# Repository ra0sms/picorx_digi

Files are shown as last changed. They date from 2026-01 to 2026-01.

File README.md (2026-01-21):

# SDR receiver Pico RX for DIGI modes

This is a clone of Jon Dawson's project [PicoRX SDR](https://github.com/dawsonjon/PicoRX).

But I wanted to make a simple DIGI (WSPR, FT8) receiver. This modification works with PC and WSJT-X software by one USB Type-C cable. 3.5 mm audio output is just for sound control. Audio from receiver to PC goes through USB connection.

More information - https://ra0sms.com/picorx-digi-modes

Firmware for 3 type of boards - https://github.com/ra0sms/picorx_digi/tree/main/firmware

Gerber files - https://github.com/ra0sms/picorx_digi/blob/main/KiCad/pico_rx/gerber_picorxdigi.zip

More pictures - https://github.com/ra0sms/picorx_digi/tree/main/pics

Schematic - https://github.com/ra0sms/picorx_digi/blob/main/KiCad/pico_rx/pipicorx.pdf

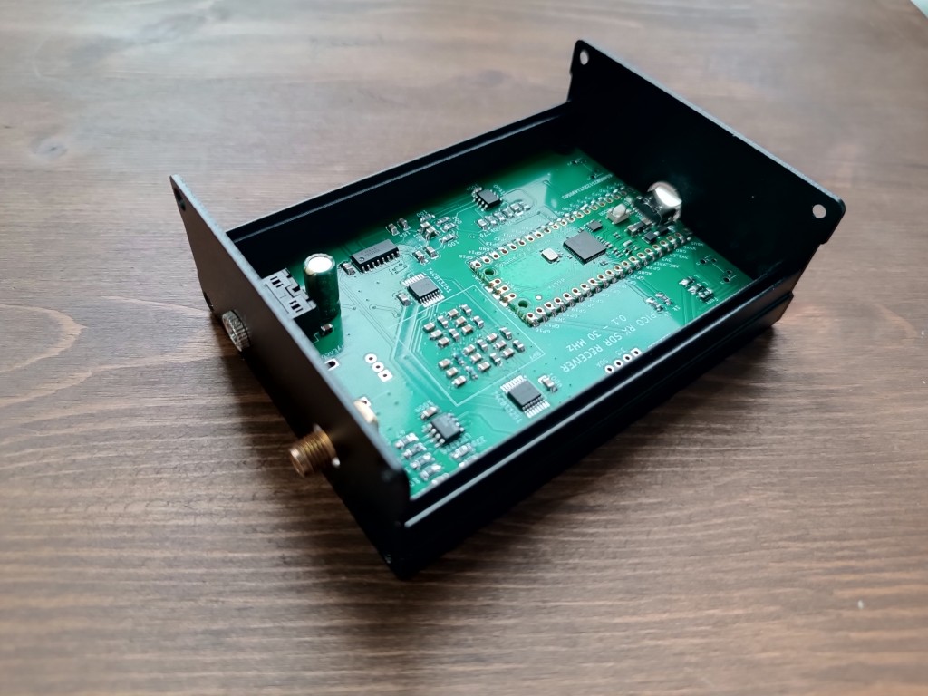
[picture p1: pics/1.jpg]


## Settings

You need to connect receiver to PC by USB cable. And select COM-port and Audio input like on the pictures below.

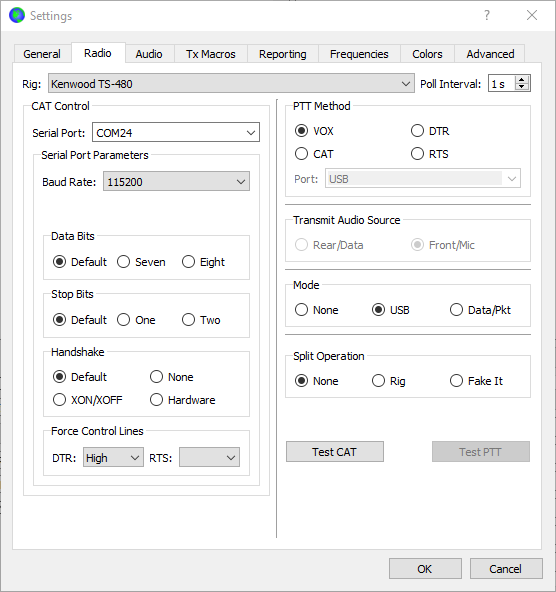
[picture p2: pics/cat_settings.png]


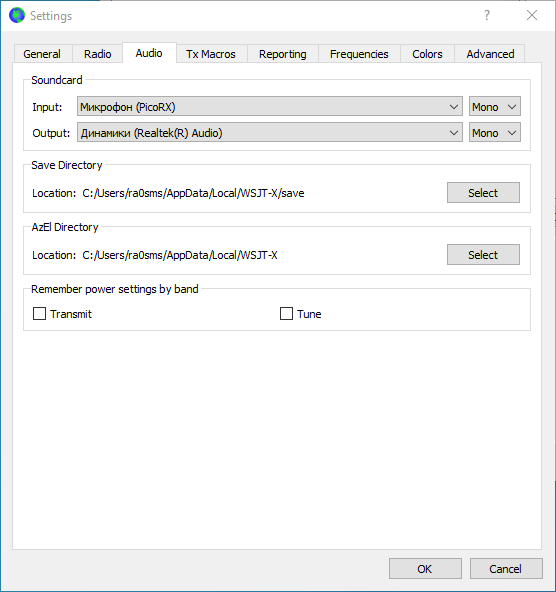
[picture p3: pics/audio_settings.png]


Or if you use FLrig software

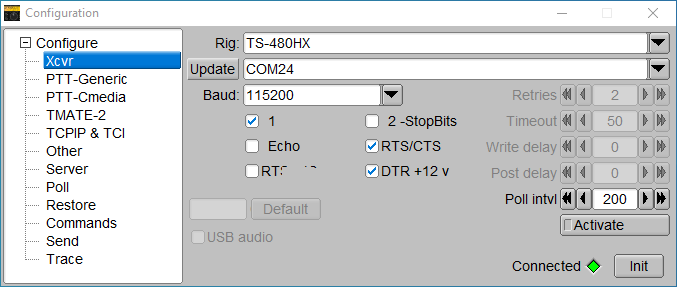
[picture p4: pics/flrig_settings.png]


Now you can see decodes.

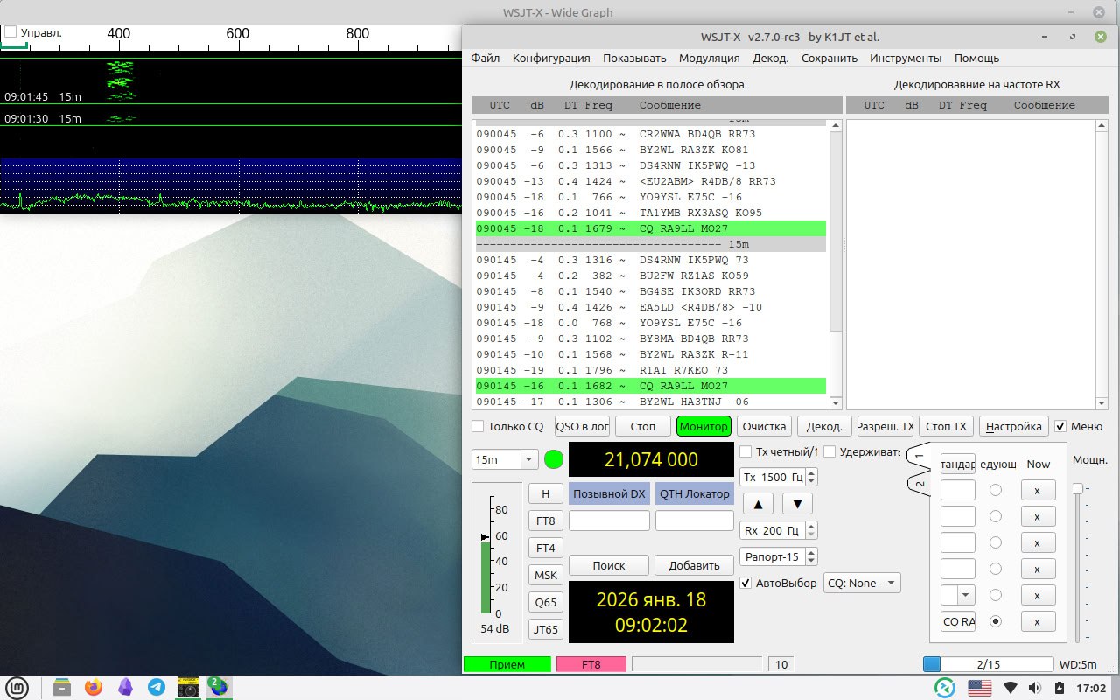
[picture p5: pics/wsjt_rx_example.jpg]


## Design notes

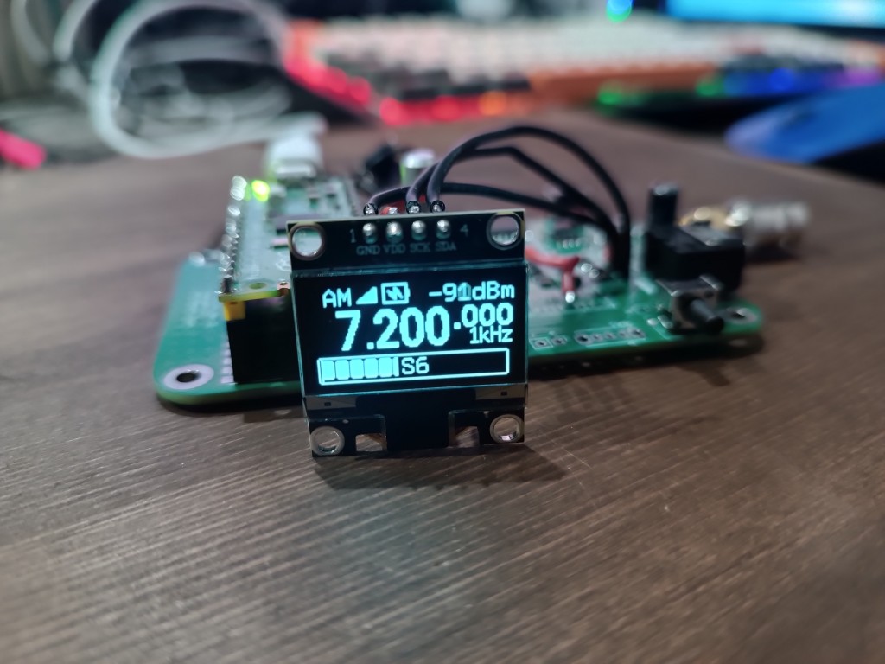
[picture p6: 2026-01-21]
pics/pipicorx_first.jpg

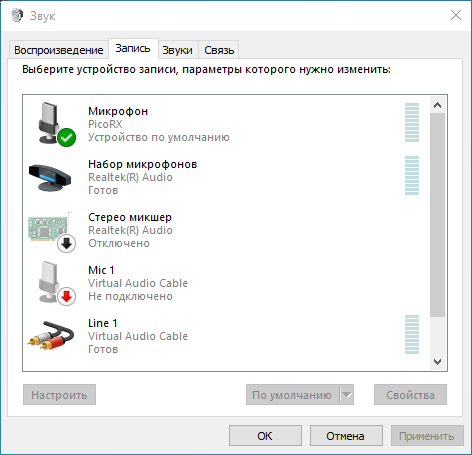
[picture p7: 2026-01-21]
pics/audio_win10.png

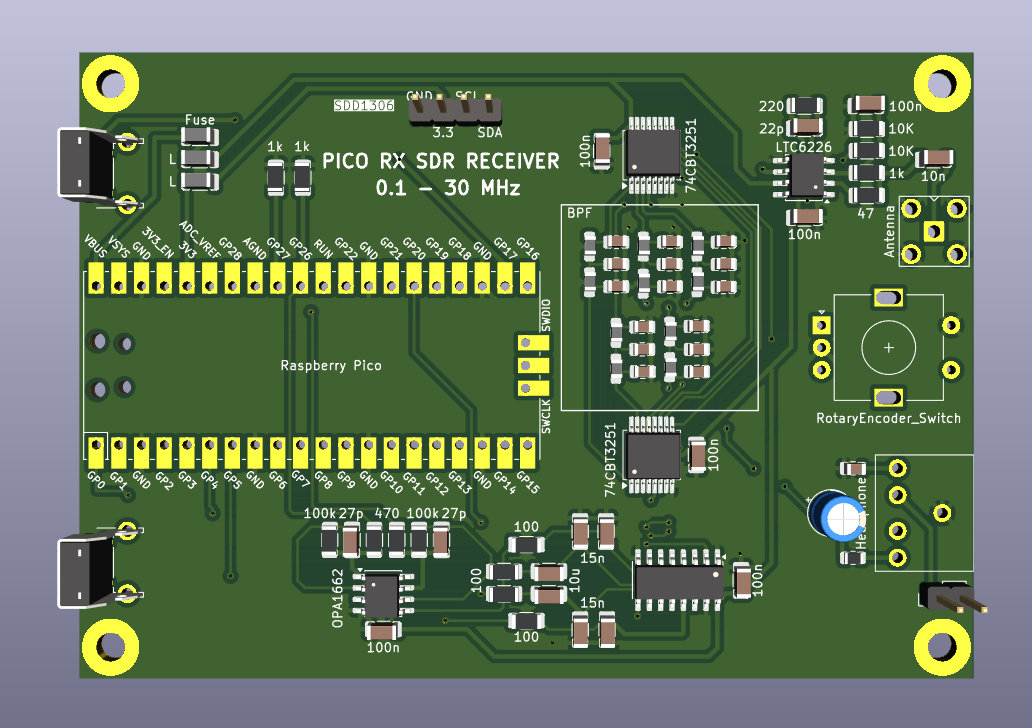
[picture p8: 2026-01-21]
pics/pico_rx_3D.png

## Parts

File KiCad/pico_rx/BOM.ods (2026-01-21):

Item | Qty | Reference(s) | Value | Footprint
1 | 1 | C1 | 10n | Capacitor_SMD:C_0805_2012Metric
2 | 6 | C2, C3, C10, C17, C24, C25 | 100n | Capacitor_SMD:C_0805_2012Metric | https://uk.farnell.com/murata/grm2195c1h103ja01d/cap-0-01-f-50v-5-c0g-np0-0805/dp/8820074
3 | 2 | C4, C11 | 10u | Capacitor_SMD:C_0805_2012Metric
4 | 1 | C5 | 22p | Capacitor_SMD:C_0805_2012Metric | https://uk.farnell.com/yageo/cc0805jrnpo9bn220/cap-22pf-50v-5-c0g-np0-0805/dp/1362555
5 | 2 | C6, C9 | 680p | Capacitor_SMD:C_0805_2012Metric | https://uk.farnell.com/multicomp/mc0805n681j101ct/cap-680pf-100v-5-c0g-np0-0805/dp/1759286
6 | 4 | C7, C13, C14, C15 | 1n | Capacitor_SMD:C_0805_2012Metric | https://uk.farnell.com/multicomp/mc0805n102j101ct/cap-1000pf-100v-5-c0g-np0-0805/dp/1759288
8 | 1 | C12 | 470p | Capacitor_SMD:C_0805_2012Metric | https://uk.farnell.com/multicomp/mca0805c471jct/cap-470pf-100v-5-c0g-np0-0805/dp/9406298
9 | 2 | C8, C16 | 330p | Capacitor_SMD:C_0805_2012Metric | https://uk.farnell.com/multicomp/mc0805n102j101ct/cap-1000pf-100v-5-c0g-np0-0805/dp/1759288
10 | 2 | C19, C22 | 1.5n | Capacitor_SMD:C_0805_2012Metric | https://uk.farnell.com/tdk/cga4c2c0g2a152j060aa/cap-1500pf-100v-5-c0g-np0-0805/dp/2210934
11 | 1 | C21 | 2.2n | Capacitor_SMD:C_0805_2012Metric | https://uk.farnell.com/tdk/cga4f2np02a222j085aa/cap-aec-q200-2200pf-100v-mlcc/dp/3651337
12 | 4 | C26, C27, C28, C29 | 15n | Capacitor_SMD:C_0805_2012Metric | https://uk.farnell.com/tdk/c2012c0g2a153j085ac/cap-0-015-f-100v-5-c0g-np0-0805/dp/2906792
13 | 2 | C30, C31 | 27p | Capacitor_SMD:C_0805_2012Metric | https://uk.farnell.com/multicomp/mc0805n270j500ct/cap-27pf-50v-5-c0g-np0-0805/dp/1759196
14 | 1 | C34 | 470n | Capacitor_SMD:C_0805_2012Metric | https://uk.farnell.com/tdk/cga4j2x7r2a153k125aa/cap-0-015-f-100v-10-x7r-0805/dp/2210963
15 | 2 | C36, C38 | 3.3n | Capacitor_SMD:C_0805_2012Metric | https://uk.farnell.com/tdk/cga4j2c0g2a332j125aa/cap-3300pf-100v-5-c0g-np0-0805/dp/2210955
16 | 1 | C37 | 4.7n | Capacitor_SMD:C_0805_2012Metric | https://uk.farnell.com/tdk/c2012np02a472j125aa/cap-4700pf-100v-mlcc-0805/dp/3651052
17 | 1 | C39 | 100u | Capacitor_Tantalum_SMD:CP_EIA-3528-21_Kemet-B | https://uk.farnell.com/kemet/t591b107m004ate045/cap-100uf-4v-tant-polymer-case/dp/3521846
18 | 2 | FB1, FB2 | Ferrite_Bead | Inductor_SMD:L_0805_2012Metric | https://uk.farnell.com/tdk/mmz2012y102b/ferrite-bead-0-3ohm-500ma-0805/dp/1669727
20 | 1 | J1 | Speaker | Connector_PinHeader_2.54mm:PinHeader_1x02_P2.54mm_Vertical | https://uk.farnell.com/pro-signal/abs-245-rc/speaker-0-5w-10khz-8-ohm/dp/2783054
21 | 1 | J2 | Headphone | reciever:jack3.5mm switched | https://uk.farnell.com/cliff-electronic-components/fc68133/stereo-jack-3-5mm-5pos-pcb/dp/2518190
22 | 1 | J4 | I2C Display | reciever:SDD1306 | https://www.amazon.co.uk/dp/B08ZKW6KM1?ref_=pe_27063361_487360311_302_E_DDE_dt_1&th=1
23 | 1 | J5 | Antenna | Connector_Coaxial:SMA_Samtec_SMA-J-P-X-ST-EM1_EdgeMount | https://uk.farnell.com/rf-solutions/con-sma-edge-s/sma-female-connector-pcb-edge/dp/3498459
24 | 1 | J6 | Battery | Connector_PinHeader_2.54mm:PinHeader_1x02_P2.54mm_Vertical | https://www.amazon.co.uk/dp/B00OK6BFGS/ref=pe_27063361_485629781_TE_item
25 | 2 | L1, L2 | 330n | Inductor_SMD:L_0805_2012Metric_Pad1.05x1.20mm_HandSolder | https://uk.farnell.com/multicomp/mcft000101/inductor-330nh-0603/dp/1711816
26 | 2 | L3, L4 | 1u | Inductor_SMD:L_0805_2012Metric_Pad1.05x1.20mm_HandSolder | https://uk.farnell.com/multicomp/mcft000128/inductor-1000nh-0805/dp/1711847
27 | 2 | L5, L13 | 220n | Inductor_SMD:L_0805_2012Metric_Pad1.05x1.20mm_HandSolder | https://uk.farnell.com/multicomp/mcft000120/inductor-220nh-0805/dp/1711838
28 | 2 | L6, L7 | 2.2u | Inductor_SMD:L_0805_2012Metric_Pad1.05x1.20mm_HandSolder | https://uk.farnell.com/multicomp/mcft000130/inductor-2200nh-0805/dp/1711849
29 | 2 | L8, L9 | 4.7u | Inductor_SMD:L_0805_2012Metric_Pad1.05x1.20mm_HandSolder | https://uk.farnell.com/multicomp/mcft000132/inductor-4700nh-0805/dp/1711851
30 | 1 | R1 | 47 | Resistor_SMD:R_0805_2012Metric | https://uk.farnell.com/walsin/wf08p47r0ftl/res-47r-1-0-25w-0805-thick-film/dp/2670099
31 | 2 | R2, R10 | 10K | Resistor_SMD:R_0805_2012Metric | https://uk.farnell.com/vishay/crcw080510k0fkta/res-10k-1-0-125w-0805-thick-film/dp/1652909
32 | 5 | R3, R4, R5, R6, R9 | 100 | Resistor_SMD:R_0805_2012Metric | https://uk.farnell.com/multicomp/mc01w08051100r/res-100r-1-0-1w-0805-thick-film/dp/9332375
33 | 2 | R7, R8 | 100k | Resistor_SMD:R_0805_2012Metric | https://uk.farnell.com/bourns/cr0805-fx-1003elf/res-100k-1-0-125w-0805-thick-film/dp/2333538
34 | 1 | R11 | 220 | Resistor_SMD:R_0805_2012Metric | https://uk.farnell.com/bourns/cr0805-fx-2200elf/res-220r-1-0-125w-0805-thick-film/dp/4153657
35 | 3 | R12, R15, R16 | 1k | Resistor_SMD:R_0805_2012Metric | https://uk.farnell.com/multicomp/mcwr08x1001ftl/res-1k-1-0-125w-0805-thick-film/dp/2447587
36 | 2 | R13, R14 | 470 | Resistor_SMD:R_0805_2012Metric | https://uk.farnell.com/multicomp/mcwr08x4700ftl/res-470r-1-0-125w-thick-film/dp/2447662
37 | 1 | SW1 | RotaryEncoder_Switch | Rotary_Encoder:RotaryEncoder_Alps_EC11E-Switch_Vertical_H20mm | https://uk.farnell.com/tt-electronics-bi-technologies/en11-hsm1af15/incremental-encoder/dp/1782717
38 | 2 | SW2, SW3 | SW_Push | Button_Switch_THT:SW_Tactile_SPST_Angled_PTS645Vx31-2LFS | https://uk.farnell.com/alps/skhhlma010/switch-tactile-pcb-r-a-0-98n/dp/1656426
39 | 1 | SW4 | SW_SPDT | Button_Switch_THT:SW_Slide_1P2T_CK_OS102011MS2Q | https://uk.farnell.com/c-k-components/os102011ma1qn1/switch-spdt-0-1a-12v-pcb-r-a/dp/1201431
40 | 2 | U1, U2 | 74CBT3251 | Package_SO:SOIC-16_3.9x9.9mm_P1.27mm | https://www.digikey.co.uk/en/products/detail/SN74CBT3251DR/296-49883-1-ND/9462753?so=64190438
41 | 1 | U3 | LTC6227 | Package_SO:MSOP-8-1EP_3x3mm_P0.65mm_EP1.68x1.88mm | https://uk.farnell.com/analog-devices/ltc6227ims8e-pbf/op-amp-420mhz-40-to-85deg-c-msop/dp/4021288
42 | 1 | U4 | FST3253 | Package_SO:SOIC-16_3.9x9.9mm_P1.27mm | https://www.digikey.co.uk/en/products/detail/rochester-electronics-llc/FST3253MX/12618585
43 | 1 | U5 | Pico | reciever:RPi_Pico_SMD_TH | https://thepihut.com/products/raspberry-pi-pico?variant=41925332533443&currency=GBP
44 | 1 | U6 | LTC6226xS8 | Package_SO:SO-8_3.9x4.9mm_P1.27mm | https://uk.farnell.com/analog-devices/ltc6226hs8-pbf/op-amp-420mhz-40-to-125deg-c-nsoic/dp/4021281

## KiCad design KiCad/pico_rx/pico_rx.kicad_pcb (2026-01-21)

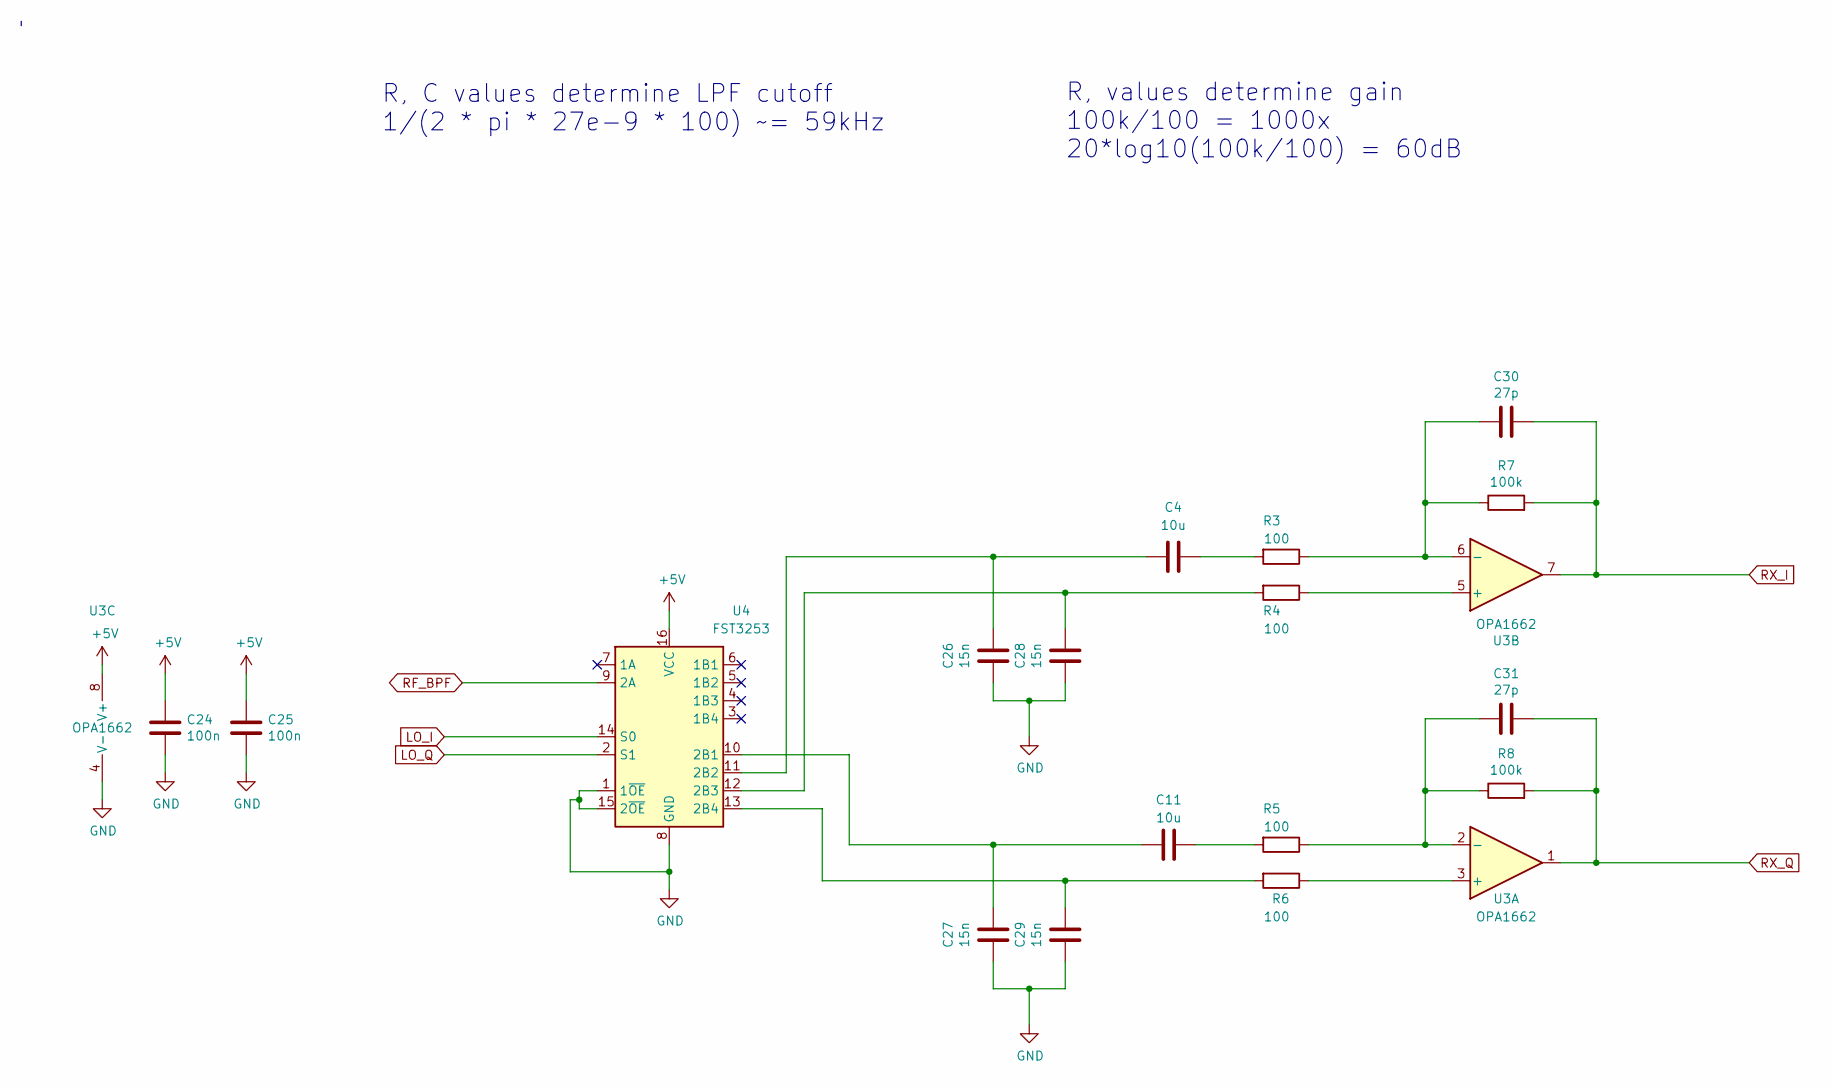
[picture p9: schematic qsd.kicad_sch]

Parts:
C4, C11: 10u; C_1206_3216Metric
C24, C25: 100n; C_1206_3216Metric
C26, C27, C28, C29: 15n; C_1206_3216Metric
C30, C31: 27p; C_1206_3216Metric
R3, R4, R5, R6: 100; R_1206_3216Metric
R7, R8: 100k; R_1206_3216Metric
U3: OPA1662; SO-8_3.9x4.9mm_P1.27mm
U4: FST3253; SOIC-16_3.9x9.9mm_P1.27mm

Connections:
+5V: C24.1, C25.1, U3.8 (V+), U4.16 (VCC); also elsewhere on the board
GND: C24.2, C25.2, C26.1, C27.1, C28.1, C29.1, U3.4 (V-), U4.1 (1~OE), U4.8 (GND), U4.15 (2~OE); also elsewhere on the board
LO_I: U4.14 (S0); also elsewhere on the board
LO_Q: U4.2 (S1); also elsewhere on the board
unnamed: C4.1, R3.2
unnamed: C11.1, R5.2
unnamed: R6.1, U3.3 (+)
unnamed: C31.1, R5.1, R8.1, U3.2 (-)
unnamed: R4.1, U3.5 (+)
unnamed: C30.1, R3.1, R7.1, U3.6 (-)
unnamed: C11.2, C27.2, U4.10 (2B1)
unnamed: C4.2, C26.2, U4.11 (2B2)
unnamed: C28.2, R4.2, U4.12 (2B3)
unnamed: C29.2, R6.2, U4.13 (2B4)
RF_BPF: U4.9 (2A); also elsewhere on the board
RX_I: C30.2, R7.2, U3.7; also elsewhere on the board
RX_Q: C31.2, R8.2, U3.1; also elsewhere on the board

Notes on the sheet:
R, values determine gain 100k/100 = 1000x 20*log10(100k/100) = 60dB
R, C values determine LPF cutoff 1/(2 * pi * 27e-9 * 100) ~= 59kHz

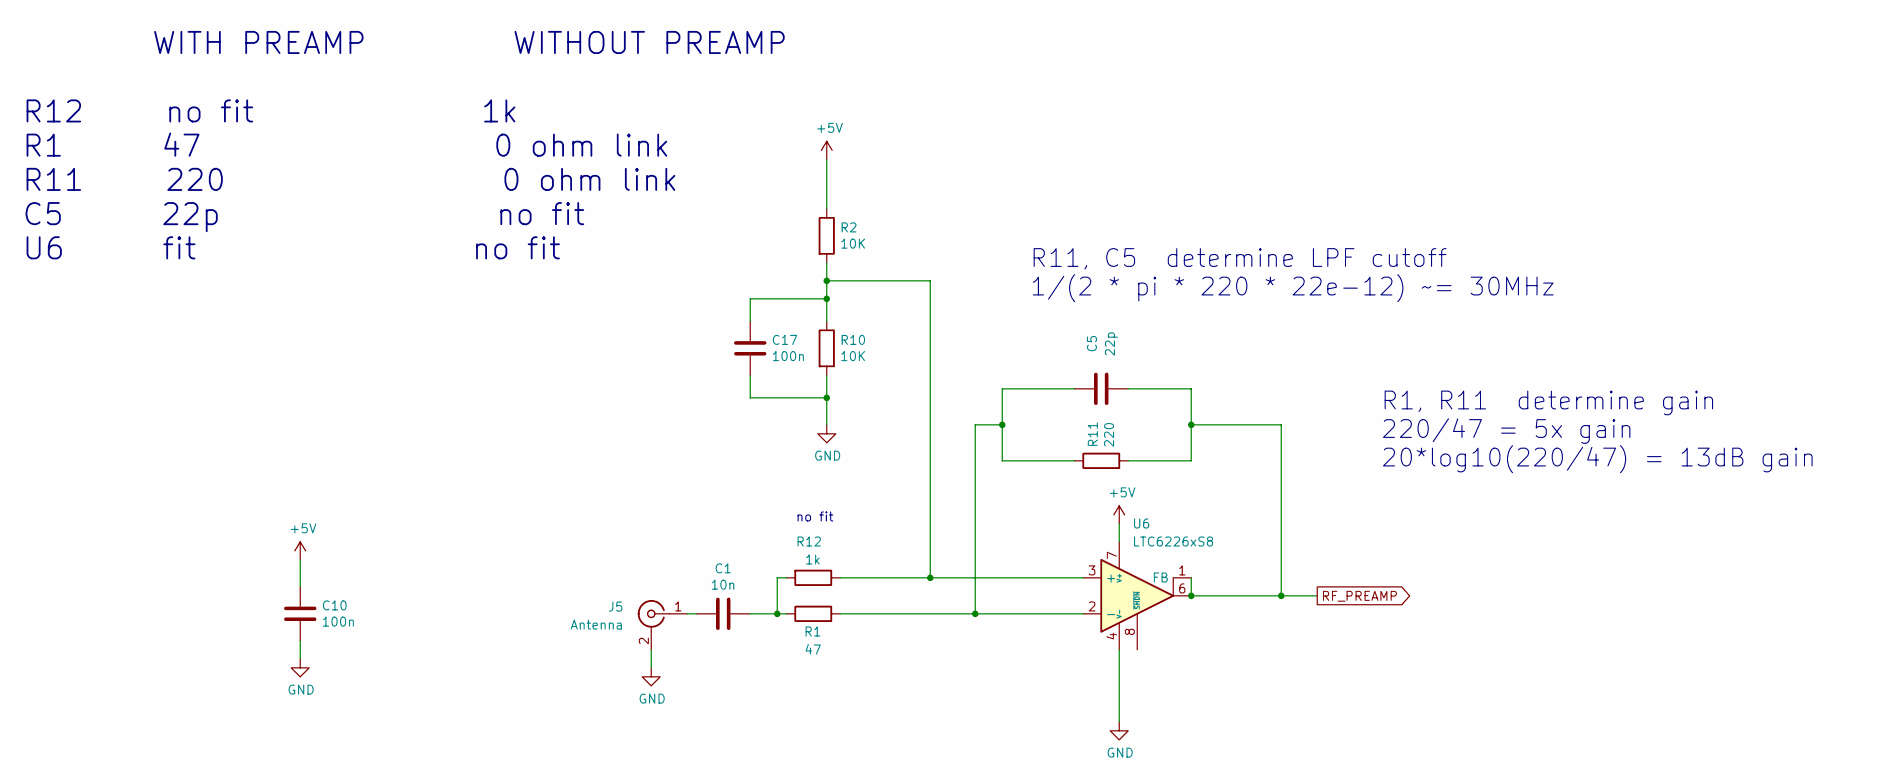
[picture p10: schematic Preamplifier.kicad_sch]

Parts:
C1: 10n; C_1206_3216Metric
C5: 22p; C_1206_3216Metric
C10, C17: 100n; C_1206_3216Metric
J5: Antenna; SMA_BAT_Wireless_BWSMA-KWE-Z001
R1: 47; R_1206_3216Metric
R2, R10: 10K; R_1206_3216Metric
R11: 220; R_1206_3216Metric
R12: 1k; R_1206_3216Metric
U6: LTC6226xS8; SO-8_3.9x4.9mm_P1.27mm

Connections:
+5V: C10.1, R2.1, U6.7 (V+); also elsewhere on the board
GND: C10.2, C17.2, J5.2 (Ext), R10.2, U6.4 (V-), U6.5 (V-); also elsewhere on the board
unnamed: C1.1, R1.1, R12.2
unnamed: C1.2, J5.1 (In)
unnamed: C17.1, R2.2, R10.1, R12.1, U6.3 (+)
unnamed: C5.1, R1.2, R11.1, U6.2 (-)
RF_PREAMP: C5.2, R11.2, U6.1 (FB), U6.6; also elsewhere on the board

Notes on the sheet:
no fit
R11, C5 determine LPF cutoff 1/(2 * pi * 220 * 22e-12) ~= 30MHz
WITH PREAMP WITHOUT PREAMP R12 no fit 1k R1 47 0 ohm link R11 220 0 ohm link C5 22p no fit U6 fit no fit
R1, R11 determine gain 220/47 = 5x gain 20*log10(220/47) = 13dB gain

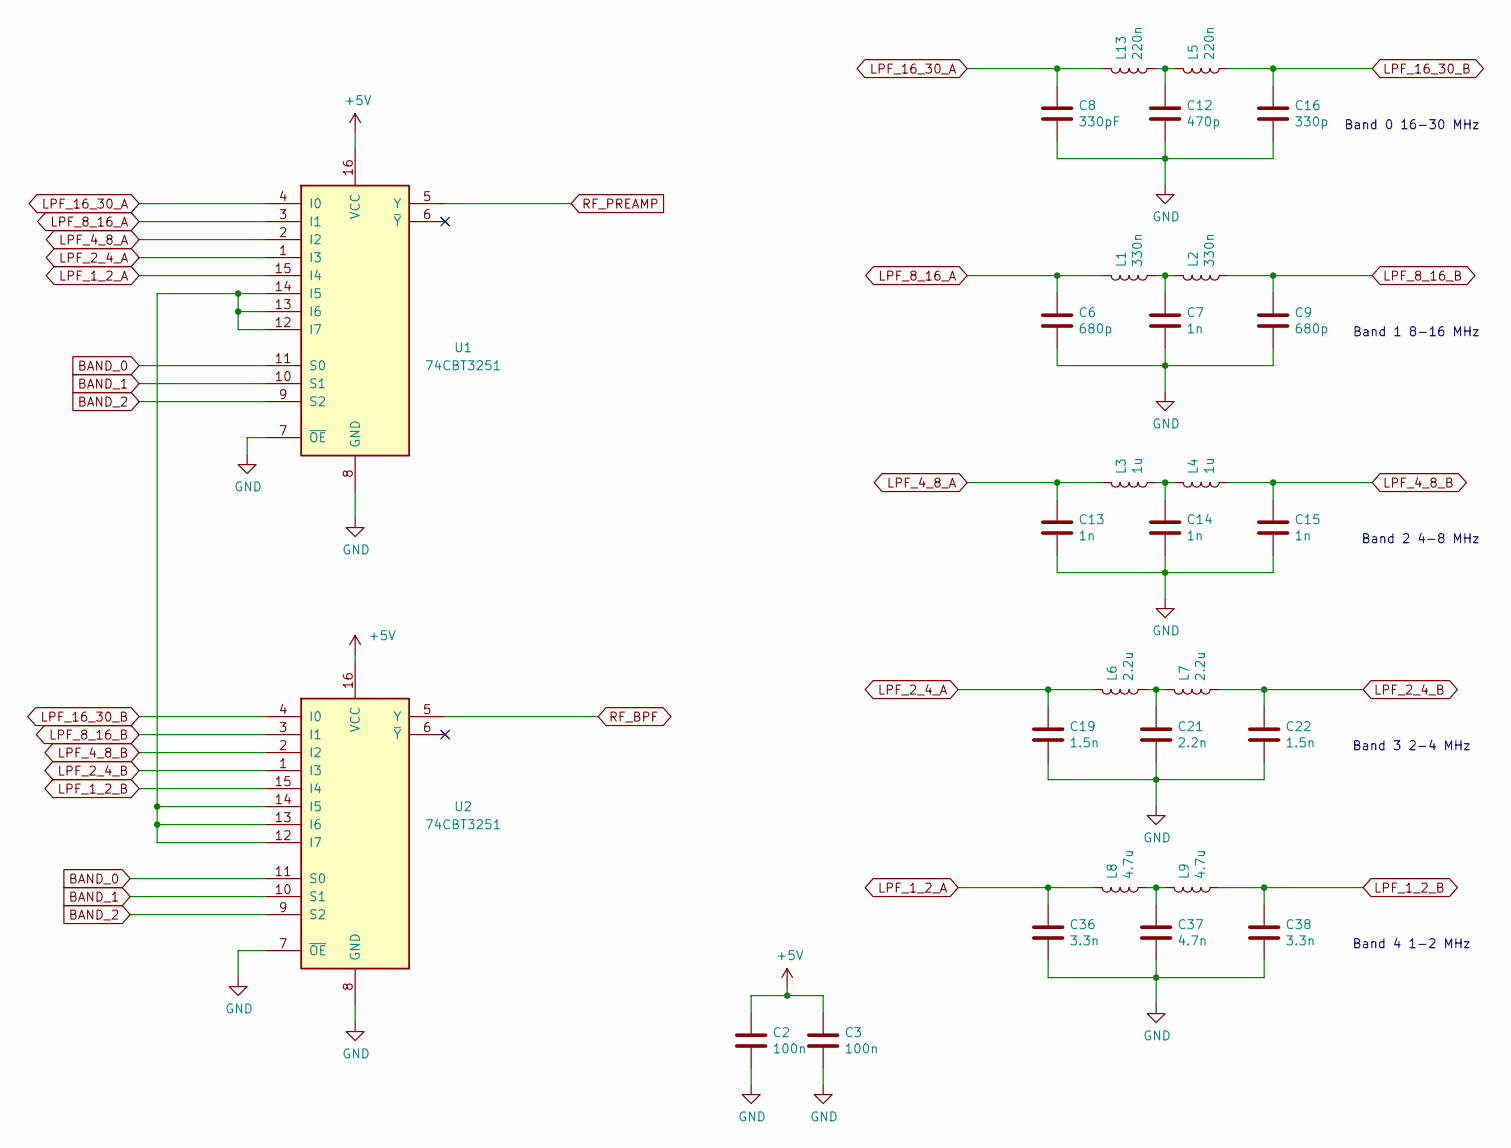
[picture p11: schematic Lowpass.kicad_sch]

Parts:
C2, C3: 100n; C_1206_3216Metric
C6, C9: 680p; C_0805_2012Metric
C7, C13, C14, C15: 1n; C_0805_2012Metric
C8: 330pF; C_0805_2012Metric
C12: 470p; C_0805_2012Metric
C16: 330p; C_0805_2012Metric
C19, C22: 1.5n; C_0805_2012Metric
C21: 2.2n; C_0805_2012Metric
C36, C38: 3.3n; C_0805_2012Metric
C37: 4.7n; C_0805_2012Metric
L1, L2: 330n; L_0805_2012Metric_Pad1.05x1.20mm_HandSolder
L3, L4: 1u; L_0805_2012Metric_Pad1.05x1.20mm_HandSolder
L5, L13: 220n; L_0805_2012Metric_Pad1.05x1.20mm_HandSolder
L6, L7: 2.2u; L_0805_2012Metric_Pad1.05x1.20mm_HandSolder
L8, L9: 4.7u; L_0805_2012Metric_Pad1.05x1.20mm_HandSolder
U1, U2: 74CBT3251; SSOP-16_5.3x6.2mm_P0.65mm

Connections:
+5V: C2.1, C3.1, U1.16 (VCC), U2.16 (VCC); also elsewhere on the board
BAND_0: U1.11 (S0), U2.11 (S0); also elsewhere on the board
BAND_1: U1.10 (S1), U2.10 (S1); also elsewhere on the board
BAND_2: U1.9 (S2), U2.9 (S2); also elsewhere on the board
GND: C2.2, C3.2, C6.1, C7.1, C8.1, C9.1, C12.1, C13.1, C14.1, C15.1, C16.1, C19.1, C21.1, C22.1, C36.1, C37.1, C38.1, U1.7 (~OE), U1.8 (GND), U2.7 (~OE), U2.8 (GND); also elsewhere on the board
LPF_1_2_A: C36.2, L8.2, U1.15 (I4)
LPF_1_2_B: C38.2, L9.1, U2.15 (I4)
LPF_2_4_A: C19.2, L6.2, U1.1 (I3)
LPF_2_4_B: C22.2, L7.1, U2.1 (I3)
LPF_4_8_A: C13.2, L3.2, U1.2 (I2)
LPF_4_8_B: C15.2, L4.1, U2.2 (I2)
LPF_8_16_A: C6.2, L1.2, U1.3 (I1)
LPF_8_16_B: C9.2, L2.1, U2.3 (I1)
LPF_16_30_A: C8.2, L13.2, U1.4 (I0)
LPF_16_30_B: C16.2, L5.1, U2.4 (I0)
unnamed: C7.2, L1.1, L2.2
unnamed: C12.2, L5.2, L13.1
unnamed: C14.2, L3.1, L4.2
unnamed: C21.2, L6.1, L7.2
unnamed: C37.2, L8.1, L9.2
unnamed: U1.12 (I7), U1.13 (I6), U1.14 (I5), U2.12 (I7), U2.13 (I6), U2.14 (I5)
RF_BPF: U2.5 (Y); also elsewhere on the board
RF_PREAMP: U1.5 (Y); also elsewhere on the board

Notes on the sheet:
Band 2 4-8 MHz
Band 4 1-2 MHz
Band 1 8-16 MHz
Band 3 2-4 MHz
Band 0 16-30 MHz

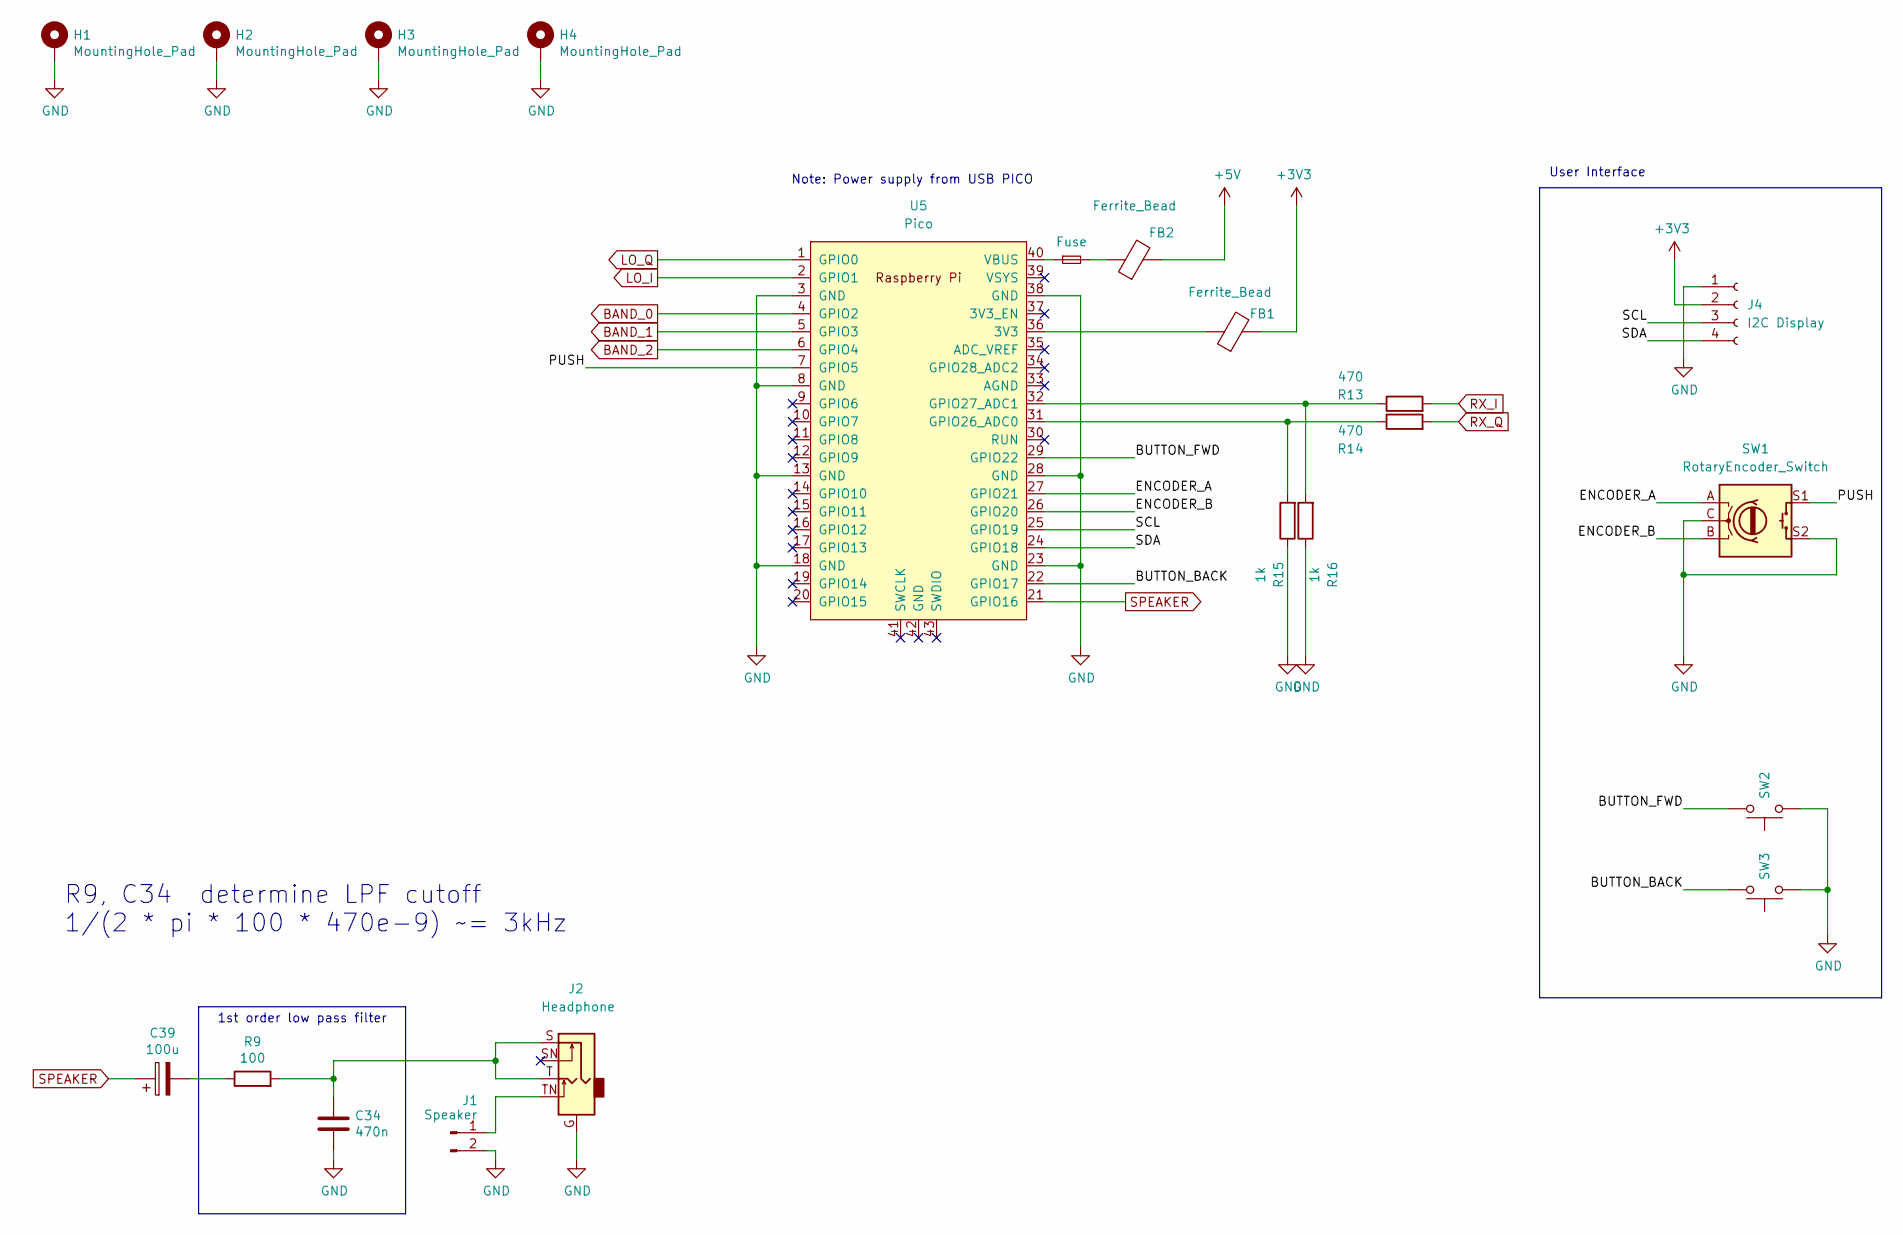
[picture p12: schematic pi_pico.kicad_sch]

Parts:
C34: 470n; C_0805_2012Metric
C39: 100u; CP_Radial_D5.0mm_P2.50mm
F1: Fuse; L_1206_3216Metric
FB1, FB2: Ferrite_Bead; L_1206_3216Metric
H1, H2, H3, H4: MountingHole_Pad; MountingHole_3.2mm_M3_Pad
J1: Speaker; PinHeader_1x02_P2.54mm_Vertical
J2: Headphone; jack3.5mm switched
J4: I2C Display; SDD1306
R9: 100; R_0805_2012Metric
R13, R14: 470; R_1206_3216Metric
R15, R16: 1k; R_1206_3216Metric
SW1: RotaryEncoder_Switch; RotaryEncoder_Alps_EC11E-Switch_Vertical_H20mm
SW2, SW3: SW_Push; SW_Tactile_SPST_Angled_PTS645Vx31-2LFS
U5: Pico; RPi_Pico_SMD_TH

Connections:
+3V3: FB1.2, J4.2
+5V: FB2.2; also elsewhere on the board
/PI Pico/BUTTON_BACK: SW3.2, U5.22 (GPIO17)
/PI Pico/BUTTON_FWD: SW2.2, U5.29 (GPIO22)
/PI Pico/ENCODER_A: SW1.A, U5.27 (GPIO21)
/PI Pico/ENCODER_B: SW1.B, U5.26 (GPIO20)
/PI Pico/PUSH: SW1.S1, U5.7 (GPIO5)
/PI Pico/SCL: J4.3, U5.25 (GPIO19)
/PI Pico/SDA: J4.4, U5.24 (GPIO18)
BAND_0: U5.4 (GPIO2); also elsewhere on the board
BAND_1: U5.5 (GPIO3); also elsewhere on the board
BAND_2: U5.6 (GPIO4); also elsewhere on the board
GND: C34.2, H1.1, H2.1, H3.1, H4.1, J1.2, J2.G, J4.1, R15.1, R16.1, SW1.C, SW1.S2, SW2.1, SW3.1, U5.3 (GND), U5.8 (GND), U5.13 (GND), U5.18 (GND), U5.23 (GND), U5.28 (GND), U5.38 (GND); also elsewhere on the board
LO_I: U5.2 (GPIO1); also elsewhere on the board
LO_Q: U5.1 (GPIO0); also elsewhere on the board
unnamed: C34.1, J2.S, J2.T, R9.2
unnamed: C39.2, R9.1
unnamed: F1.2, FB2.1
unnamed: J1.1, J2.TN
unnamed: FB1.1, U5.36 (3V3)
unnamed: R14.1, R15.2, U5.31 (GPIO26_ADC0)
unnamed: R13.1, R16.2, U5.32 (GPIO27_ADC1)
unnamed: F1.1, U5.40 (VBUS)
RX_I: R13.2; also elsewhere on the board
RX_Q: R14.2; also elsewhere on the board
SPEAKER: C39.1, U5.21 (GPIO16)

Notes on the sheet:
1st order low pass filter
Note: Power supply from USB PICO
User Interface
R9, C34 determine LPF cutoff 1/(2 * pi * 100 * 470e-9) ~= 3kHz

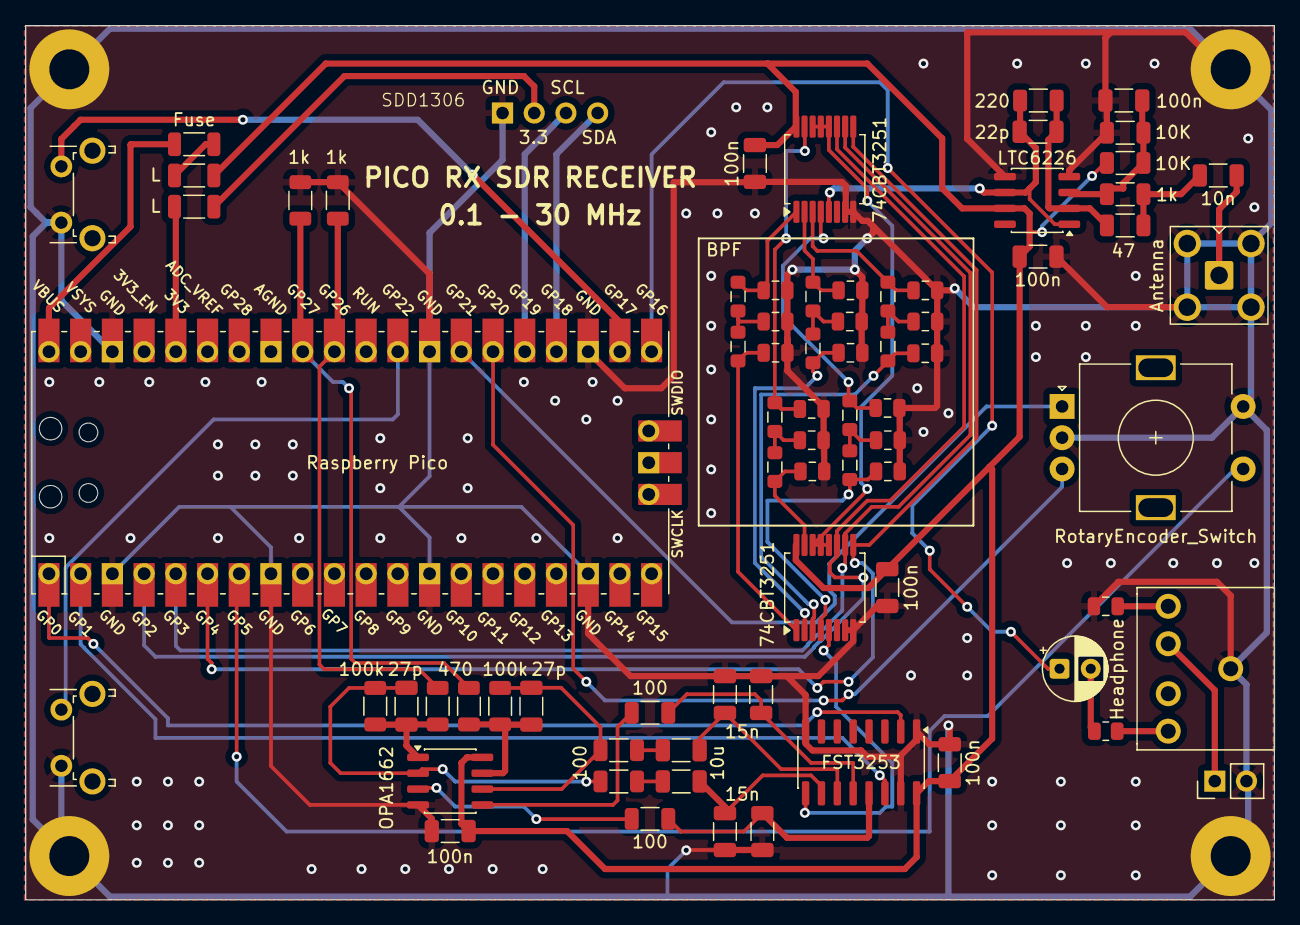
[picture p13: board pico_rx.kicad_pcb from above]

Board: 2 copper layers, 100.0 x 70.0 mm, 79 parts (0 on the bottom side), 58 nets.
